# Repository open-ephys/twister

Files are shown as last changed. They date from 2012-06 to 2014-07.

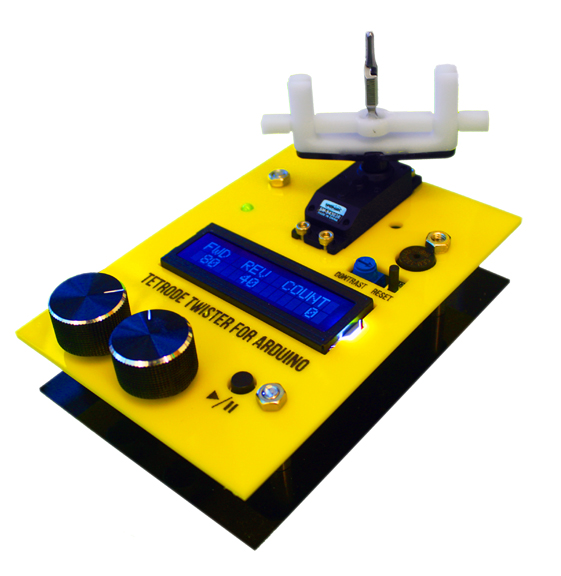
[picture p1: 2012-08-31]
images/twister.jpg

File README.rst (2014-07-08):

=================================
An open-source tetrode twister for Arduino
=================================

This code requires the `Arduino <http://www.arduino.cc>`_ development environment and an `Arduino board <http://www.sparkfun.com/products/11021>`_. 

The code has been updated to be compatible with the Arduino IDE version 1.0 and higher. To make it compatible with earlier versions of the IDE, simply include "WProgram.h" instead of "Arduino.h" in the TwisterClasses.h file.

This repository contains circuit board files, a parts list, and an instruction manual.

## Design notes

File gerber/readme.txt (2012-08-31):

1. Drill File = twister.drd
2. Bottom Soldermask = twister.smb
3. Bottom Copper Layer = twister.bot
4. Top Copper Layer =  twister.top
5. Top Soldermask Layer = twister.smt
6. Top Silkscreen Layer = twister.slk
7. Board Outline = twister.oln

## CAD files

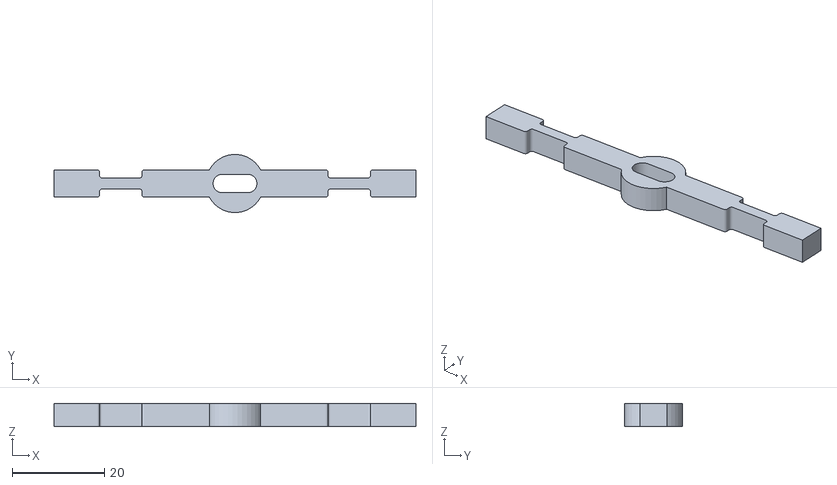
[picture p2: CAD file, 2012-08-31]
case/clip_holder.stl
78.4 x 12.6 x 5.00

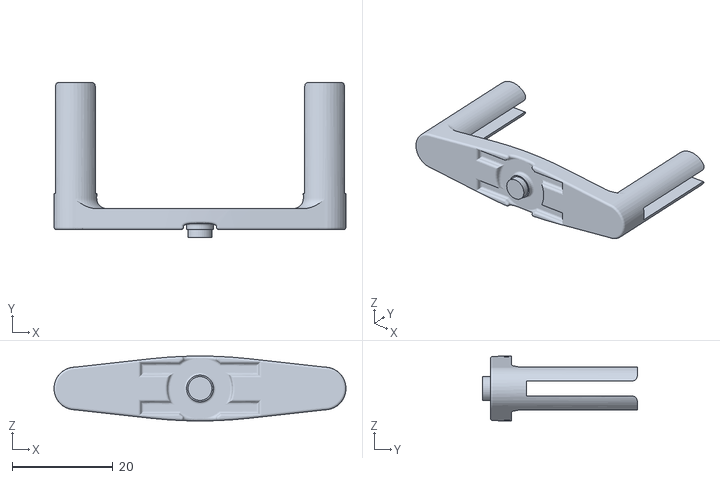
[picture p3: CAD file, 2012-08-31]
case/guide_posts.stl
58.0 x 30.7 x 12.9

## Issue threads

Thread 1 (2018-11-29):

Twister only twists one direction

r4chelp, 2018-11-29:
I have a pre-built Tetrode Twister (ordered from Open Ephys) that appears functional (LCD, counter are working), except that it only twists in one direction. I tried reloading the Arduino software but still doesn't reverse direction after forward count ends.

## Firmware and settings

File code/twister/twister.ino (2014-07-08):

 //    Tetrode Twister Control Software
//    Copyright (C) 2011 Josh Siegle
//
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

// ------------------------------ //
//    SOFTWARE VERSION NUMBER:
int ver[2] = {
  3, 1};
// ------------------------------ //
//    PCB VERSION NUMBER:
int verPCB = 1; 

// -------------------------------------------------------------------- //
/*    DEBUG MODE?
 
 If debugMode is set to 'true', photocell values and thresholds
 will be printed to the serial port. These can be visualized 
 using the accompanying Processing sketch, 'PhotocellVisualization.pde'
 
 If printState is set to 'true', total turns, forward turns, reverse turns,
 button state, and counter state will be printed to the serial port.
 
 */
 
boolean debugMode = true;
boolean printState = false;

/*   SAVE STATE?

 If saveState is set to true, the Arduino will save its current status
 after each turn. The state can then be restored if the Arduino loses
 power or is reset while turning.

*/

boolean saveState = false;

// -------------------------------------------------------------------- //

// BEGIN ACTUAL CODE:

// Includes
#include <Servo.h>
#include <LiquidCrystal.h>
#include <EEPROM.h>
#include "TwisterClasses.h"

// Initialize servo and LCD
Servo myservo;
const int servoPin = 9;
LiquidCrystal lcd(12,11,5,4,3,2);

// Initialize twister classes

//Board 1.1
Buzzer buzzer(6); // Board 1.1 = 6, Board 1.0 = 7
Inputs inputs(7,0,1); // Board 1.1 = 7, Board 1.0 = 6

StateTracker twister;
Photocells photocells(2, 3);

// EEPROM variables
int remainingTurns;
int turnDirection;

void setup()
{

  // start up servo and LCD screen
  myservo.attach(servoPin);
  lcd.begin(16,2);

  if (debugMode || printState) {
    Serial.begin(9600);
  }

  // Read from EEPROM to determine if an error occurred during the last twist:
  if (saveState) {
    remainingTurns = EEPROM.read(0);
    turnDirection = EEPROM.read(1);
  }

  //if (remainingTurns == 0 || remainingTurns == 255) {
    startupScreen(ver[0],ver[1]);  // Display the welcome message

  //} // NOT CURRENTLY IMPLEMENTED:
  //       if Arduino loses power or is reset while turning, 
  //       the program will read stored values from EEPROM
  //       and keep turning where it left off.
  
  //else { // restart turning
  //  resumeDialog();  //Display the interactive dialog
  //}

}

void loop()
{
  inputs.check(twister.isTurning, verPCB);

  if (twister.isTurning) { // only update photocells if twister is spinning
    int turns = photocells.update(twister.isTurningFWD,millis());

    if (turns) {
      twister.totalTurns += turns;
      twister.isUpdated = true; // necessary to update LCD

      if (printState) {
        printVariables();
      }
    }
  }

  showTurns(); // update LCD screen

  if (inputs.buttonState == LOW) { // check for button press
    twister.respondToButton();
    delay(250);
  }

  updateServo();
  
  if (saveState) {
    updateEEPROM();
  }

  if (debugMode) {
    printPhotocellInfo();
  }

}

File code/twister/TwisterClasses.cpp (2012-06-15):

//    Tetrode Twister Control Software
//    Copyright (C) 2011 Josh Siegle
//
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

#include "TwisterClasses.h"

// Buzzer methods:

Buzzer::Buzzer(int pin)
{
  pinMode(pin, OUTPUT);
  _pin = pin;
}

void Buzzer::high()
{
  tone(_pin,2000,200);
}

void Buzzer::low()
{
  tone(_pin,1000,200);
}

// Inputs methods:

Inputs::Inputs(int pin1, int pin2, int pin3)
{
  pinMode(pin1, INPUT);
  _buttonPin = pin1;
  _knobPin1 = pin2;
  _knobPin2 = pin3;
  buttonState = 0;
  fwdTurns = 0;
  revTurns = 0;
  isUpdated = true;
}

void Inputs::check(boolean isTurning, int verPCB)
{
  buttonState = digitalRead(_buttonPin); // read button state
  int knob1;
  int knob2;


  if (!isTurning) { // allow changes only if twister isn't turning

      if (verPCB) {
      // Board ver 1.1:
      knob1 = analogRead(_knobPin1) / 4 * 100 / 255;
      knob2 = analogRead(_knobPin2) / 4 * 100 / 255;
    } 
    else {
      // Board ver 1.0:
      knob1 = (255-(analogRead(_knobPin1) / 4)) * 100 / 255;
      knob2 = (255-(analogRead(_knobPin2) / 4)) * 100 / 255;
    }

    // constrain values to be between 0 and 100
    knob1 = min(knob1,100); 
    knob1 = max(knob1,0);
    knob2 = min(knob2,100); 
    knob2 = max(knob2,0);

    if (knob1 != fwdTurns || knob2 != revTurns) { // check to see if values have been updated
      isUpdated = true;
    }
    fwdTurns = knob1;
    revTurns = knob2;
  }
}


// StateTracker methods:

StateTracker::StateTracker()
{
  isTurning = false;
  isTurningFWD = true;
  isUpdated = false;
  totalTurns = 0;

}

void StateTracker::respondToButton()
{
  isTurning = !(isTurning);
}


// Photocells methods

Photocells::Photocells(int pin1, int pin2)
{
  pins[0] = pin1;
  pins[1] = pin2;
  maxVal[0] = 0; 
  maxVal[1] = 0;
  minVal[0] = 1023; 
  minVal[1] = 1023;
  counter = 0;
  nValues = 25;
  canBeTriggered[0] = true;
  canBeTriggered[1] = true; 
}


int Photocells::update(boolean dir, long time)
{
  // read in data
  values[0] = analogRead(pins[0]);
  values[1] = analogRead(pins[1]);

  checkThreshold(); // use history to dynamically set the threshold

    // check photocell 1
  if (values[0] > thresh[0] && canBeTriggered[0] && time - triggerTime[0] > 200) {
    quarterTurns += 1;
    canBeTriggered[0] = false;
    canBeTriggered[1] = true;
    triggerTime[0] = millis();
  }

  // check photocell 2
  if (values[1] > thresh[1] && canBeTriggered[1] && time - triggerTime[1] > 200) {
    quarterTurns += 1;
    canBeTriggered[1] = false;
    canBeTriggered[0] = true;
    triggerTime[1] = millis();
  }

  // check for a full rotation
  if (quarterTurns == 4) {
    quarterTurns = 0;
    if (dir) {
      return 1;
    } 
    else {
      return -1;
    }

  } 
  else {
    return 0;
  }

}

void Photocells::checkThreshold() {

  int index = counter % nValues;

  // store values in history
  history1[index] = values[0];
  history2[index] = values[1];

  if (index == 0) {
    maxVal[0] = 0;
    maxVal[1] = 0;
    minVal[0] = 1023;
    minVal[1] = 1023;
  }

  // search for max and min
  for (int n = 0; n < nValues; n++) {
    maxVal[0] = max(history1[n],maxVal[0]);
    maxVal[1] = max(history2[n],maxVal[1]);
    minVal[0] = min(history1[n],minVal[0]);
    minVal[1] = min(history2[n],minVal[1]);
  }

  // set threshold at 80% boundary between min and max
  thresh[0] = (maxVal[0] - minVal[0])*0.8 + minVal[0];
  thresh[1] = (maxVal[1] - minVal[1])*0.8 + minVal[1];

  counter += 1;

  delay(10); // wait for 10 milliseconds to make the sampling rate reasonable

}

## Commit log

2012-06-15 Updated include files for Arduino 1.0
2012-08-31 Added lots of new files
    [clip_holder.stl, guide_posts.stl, twister.brd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]
2014-12-04 Clean up servo code

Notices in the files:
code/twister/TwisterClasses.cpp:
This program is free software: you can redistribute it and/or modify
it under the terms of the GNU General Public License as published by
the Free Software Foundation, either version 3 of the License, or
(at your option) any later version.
